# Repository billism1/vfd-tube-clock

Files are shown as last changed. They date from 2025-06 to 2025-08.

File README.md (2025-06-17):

# VFD Tube Clock

This project is a WiFi-connected clock that uses an IV-21 VFD (Vacuum Fluorescent Display) tube for the display and a custom PCB controlled by an ESP32 microcontroller. Built with PlatformIO using the Arduino framework, it should work with other ESP32 variants and Arduino-compatible MCUs.

## Design Overview

The PCB is designed around the Seeeduino ESP32-C3 devboard but can be adapted for other microcontrollers. The schematic and PCB design files were created using KiCad 9.0, with firmware development in VS Code with PlatformIO.

## Project Background

This is the first time I've had PCBs printed. I've been a software developer for many years and have been dabbling in electronics as a hobby over the past couple of years. I've been fascinated by vintage display technology - there's something captivating about the warm glow and classic look of old tube displays, plus those beautiful colors that display tubes like Nixie tubes and VFDs produce. I love the idea of bridging old and new technology by controlling these vintage displays with modern microcontrollers and WiFi connectivity.

**Current Status:** I'm actively refining the PCB design based on initial testing. The photos and videos below show the first prototype batch of 5 PCBs, while the KiCad files reflect ongoing improvements to the design.

## Project Photos

<div align="center">
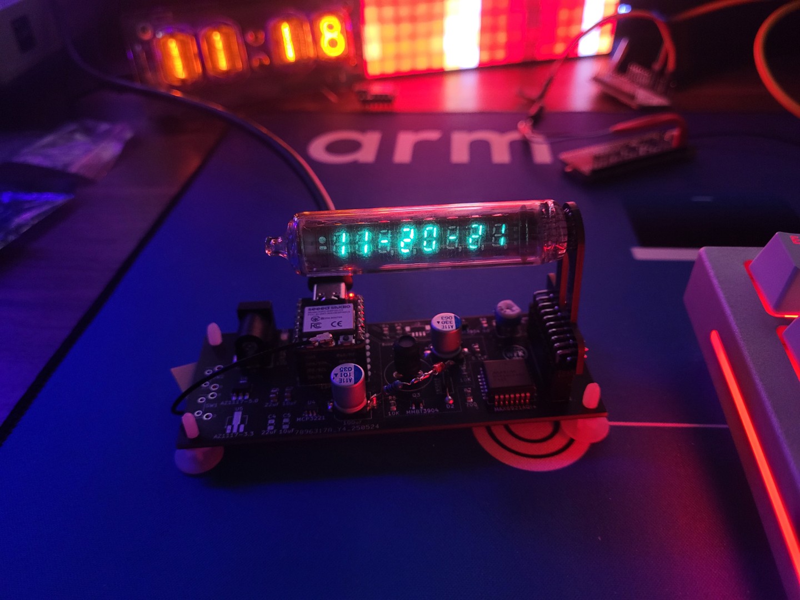
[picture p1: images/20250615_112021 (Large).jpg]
VFD Clock Front View 1

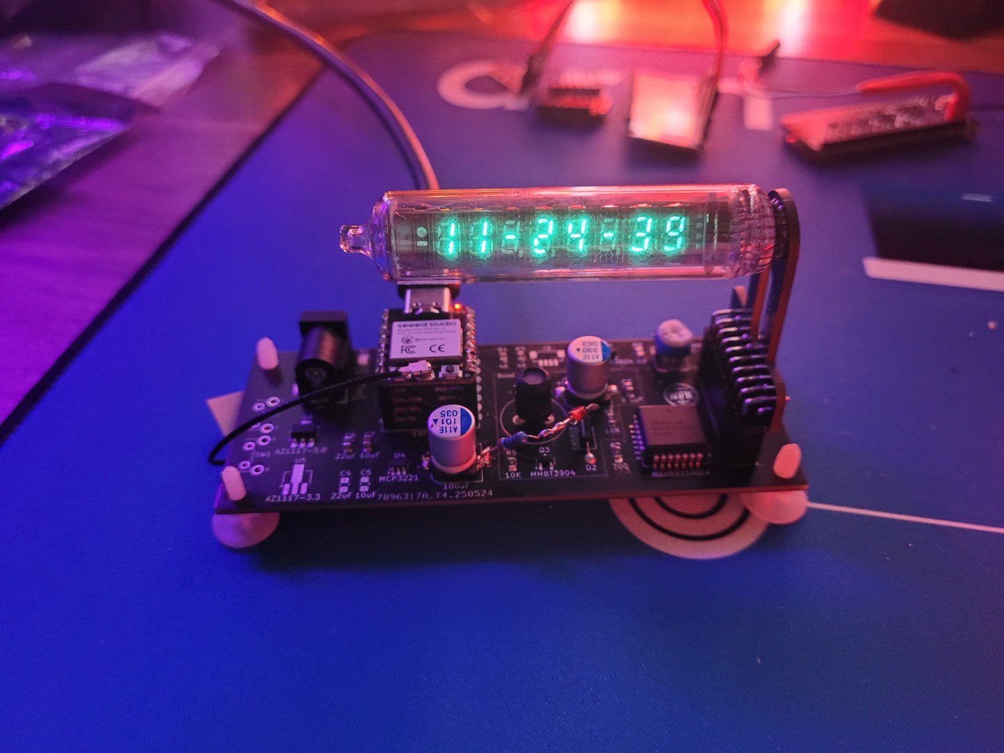
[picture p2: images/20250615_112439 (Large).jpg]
VFD Clock Front View 2

</div>

## Web Interface

Though most of the source code I wrote myself, one of my weak areas is web UI design. I used an LLM (claude.ai) to generate a Soviet themed web UI for controlling the clock over WiFi. Soviet - because these IV-21 VFD tubes were manufactured in Soviet USSR.

**[View Web Interface Screenshots in images dir →](images/)**

## Video

VFD Clock Demo Video (https://youtu.be/QAAFPpQU498)

*Click to watch the demo video*

## How VFD Tubes Work

VFDs use phosphor materials, typically zinc oxide (ZnO) doped with zinc sulfide or other compounds, that emit light when struck by electrons from a heated filament cathode. The phosphor coating on the anode segments converts the electron energy into visible light, usually producing a characteristic blue-green glow, though the exact color depends on the specific phosphor formulation. The IV-21 specifically uses a zinc-based phosphor that creates its distinctive aqua-blue appearance.

The electrical requirements involve multiple voltages: a low filament voltage to heat the cathode (~2.5V DC for the IV-21), and higher anode/grid voltages to accelerate electrons toward the phosphor-coated segments (typically ~27V DC for the IV-21).

Multiplexing is the key technique that makes multi-digit VFD clocks practical - instead of driving all digits simultaneously (which would require complex, expensive circuitry), we rapidly cycle through each digit position, lighting only one at a time. By switching between digits faster than your eye can detect (typically 100Hz or higher), each digit appears continuously lit even though it's only powered for a fraction of the time. This creates the illusion of a stable, solid display across all digits while dramatically simplifying the driver electronics.

## Key Circuit Design Components

### Voltage Booster Circuit
The VFD needs 27V but our power supply only provides 5V, so we need a boost converter to step up the voltage. This circuit works like a voltage pump - it stores energy in an inductor coil when a transistor switches on, then releases that energy at a higher voltage when the transistor switches off. A diode ensures the boosted voltage flows in the right direction, and the ESP32 generates the rapid on/off switching signal (PWM) that makes it all work.
The circuit takes our 5V input and pumps it up to the 27V needed by the MAX6921 driver chip, which then distributes power to light up the VFD segments.

### MAX6921 VFD Driver
The MAX6921 IC serves as the interface between the microcontroller and VFD tube. It receives 3 bytes of data from the ESP32 telling it which segments to illuminate, then distributes the boosted 27V to the appropriate pins at precise timing intervals for proper message display. Multiple MAX6921s can be chained together for tubes with more digits or multiple tubes.

## Software Features

### Core Functionality
- **WiFi Connectivity:** Automatic connection to configured network
- **NTP Time Sync:** Retrieves accurate time from "pool.ntp.org"
- **Web Server:** Built-in HTTP server for device control
- **Multiple Display Modes:**
  - Time display mode
  - Custom message mode
  - "Flash message" mode with glitchy visual effects

### Flash Message Mode
As a novelty feature (which can be disabled), the clock occasionally displays random words that appear to "glitch" into existence—brief flashes of random characters before settling on the final message for a brief period, creating a subliminal effect. The word selection (easily changed in code) and styling pay homage to the Soviet heritage of these VFD tubes.

## Planned Improvements

### Hardware Enhancements
- **Better Voltage Regulation**
- **Multi-digit Support:** Extend design for tubes with more digits (IV-27 with 13 digits)

### Software Features
- **Better Wifi Management:** Default to AP mode for after compilation WiFi configuration
- **Text Scrolling:** Support for messages longer than 8 characters
- **Smart PWM Control:** Implement PID algorithm for voltage regulation
- **Enhanced Web UI:** Additional control options and settings
- **Button Integration:** Assign meaningful functions to hardware buttons which are not programmed to do anything currently

## Acknowledgments

This project was heavily inspired by and references the excellent work of:

- **[Tiny IV-21 VFD Clock](https://hackaday.io/project/167749-tiny-iv-21-vfd-clock)** - Original design inspiration. At least this was the first similar project that I came across. Uses an Atmega328P microcontroller and external (to the microcontroller module) RTC (real-time clock) component.
- **[Tiny IV-21 VFD Clock with ESP32](https://hackaday.io/project/202799-tiny-iv-21-vfd-clock-with-esp32)** - ESP32 implementation inspired from the above mentioned "Tiny IV-21 VFD Clock" project. Excludes the external RTC component and uses WiFi/Internet for automatic time synchronization.

Special thanks to the creators of these projects for sharing their knowledge and making this hobby accessible to others.

## Project Organization

### Where to find stuff
- [Main board PCB KiCad design files](./pcb/main-board/)
- [Sub-board PCB (VFD tube holder) design files](./pcb/sub-board/)
- [Main board PCB gerber files (ready to print PCBs)](./pcb-fab/gerber-main-board/)
- [An interactive BOM (Bill of Materials) for the main board](./pcb-fab/gerber-main-board/bom/)
- [Sub-board PCB - VFD tube holder (ready to print PCBs)](./pcb-fab/gerber-sub-board/)
- [Source code](./firmware/) (Built with PlatformIO for simplified dependency management and cross-platform development)

## License

This project is licensed under the MIT License - see the [LICENSE](LICENSE) file for details.

## Contributing

Contributions are welcome! Please feel free to submit pull requests or open issues for bugs and feature requests.

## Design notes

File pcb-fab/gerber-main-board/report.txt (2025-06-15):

Plotted to 'C:\Users\billi\Source\repos\iv21-vfd-clock-with-esp32\pcb\main-board\gerber-output\iv21-vfd-clock-with-esp32-F_Cu.gbr'.
Plotted to 'C:\Users\billi\Source\repos\iv21-vfd-clock-with-esp32\pcb\main-board\gerber-output\iv21-vfd-clock-with-esp32-B_Cu.gbr'.
Plotted to 'C:\Users\billi\Source\repos\iv21-vfd-clock-with-esp32\pcb\main-board\gerber-output\iv21-vfd-clock-with-esp32-F_Paste.gbr'.
Plotted to 'C:\Users\billi\Source\repos\iv21-vfd-clock-with-esp32\pcb\main-board\gerber-output\iv21-vfd-clock-with-esp32-B_Paste.gbr'.
Plotted to 'C:\Users\billi\Source\repos\iv21-vfd-clock-with-esp32\pcb\main-board\gerber-output\iv21-vfd-clock-with-esp32-F_Silkscreen.gbr'.
Plotted to 'C:\Users\billi\Source\repos\iv21-vfd-clock-with-esp32\pcb\main-board\gerber-output\iv21-vfd-clock-with-esp32-B_Silkscreen.gbr'.
Plotted to 'C:\Users\billi\Source\repos\iv21-vfd-clock-with-esp32\pcb\main-board\gerber-output\iv21-vfd-clock-with-esp32-F_Mask.gbr'.
Plotted to 'C:\Users\billi\Source\repos\iv21-vfd-clock-with-esp32\pcb\main-board\gerber-output\iv21-vfd-clock-with-esp32-B_Mask.gbr'.
Plotted to 'C:\Users\billi\Source\repos\iv21-vfd-clock-with-esp32\pcb\main-board\gerber-output\iv21-vfd-clock-with-esp32-Edge_Cuts.gbr'.
Created Gerber job file 'C:\Users\billi\Source\repos\iv21-vfd-clock-with-esp32\pcb\main-board\gerber-output\iv21-vfd-clock-with-esp32-job.gbrjob'.
Info: Done.

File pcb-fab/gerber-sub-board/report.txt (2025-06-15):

Plotted to 'C:\Users\billi\Source\repos\iv21-vfd-clock-with-esp32\pcb-fab\gerber-sub-board\IV-21VFDsub-F_Cu.gbr'.
Plotted to 'C:\Users\billi\Source\repos\iv21-vfd-clock-with-esp32\pcb-fab\gerber-sub-board\IV-21VFDsub-B_Cu.gbr'.
Plotted to 'C:\Users\billi\Source\repos\iv21-vfd-clock-with-esp32\pcb-fab\gerber-sub-board\IV-21VFDsub-F_Paste.gbr'.
Plotted to 'C:\Users\billi\Source\repos\iv21-vfd-clock-with-esp32\pcb-fab\gerber-sub-board\IV-21VFDsub-B_Paste.gbr'.
Plotted to 'C:\Users\billi\Source\repos\iv21-vfd-clock-with-esp32\pcb-fab\gerber-sub-board\IV-21VFDsub-F_Silkscreen.gbr'.
Plotted to 'C:\Users\billi\Source\repos\iv21-vfd-clock-with-esp32\pcb-fab\gerber-sub-board\IV-21VFDsub-B_Silkscreen.gbr'.
Plotted to 'C:\Users\billi\Source\repos\iv21-vfd-clock-with-esp32\pcb-fab\gerber-sub-board\IV-21VFDsub-F_Mask.gbr'.
Plotted to 'C:\Users\billi\Source\repos\iv21-vfd-clock-with-esp32\pcb-fab\gerber-sub-board\IV-21VFDsub-B_Mask.gbr'.
Plotted to 'C:\Users\billi\Source\repos\iv21-vfd-clock-with-esp32\pcb-fab\gerber-sub-board\IV-21VFDsub-Edge_Cuts.gbr'.
Created Gerber job file 'C:\Users\billi\Source\repos\iv21-vfd-clock-with-esp32\pcb-fab\gerber-sub-board\IV-21VFDsub-job.gbrjob'.
Plotted to 'C:\Users\billi\Source\repos\iv21-vfd-clock-with-esp32\pcb-fab\gerber-sub-board\IV-21VFDsub-F_Cu.gbr'.
Plotted to 'C:\Users\billi\Source\repos\iv21-vfd-clock-with-esp32\pcb-fab\gerber-sub-board\IV-21VFDsub-B_Cu.gbr'.
Plotted to 'C:\Users\billi\Source\repos\iv21-vfd-clock-with-esp32\pcb-fab\gerber-sub-board\IV-21VFDsub-F_Paste.gbr'.
Plotted to 'C:\Users\billi\Source\repos\iv21-vfd-clock-with-esp32\pcb-fab\gerber-sub-board\IV-21VFDsub-B_Paste.gbr'.
Plotted to 'C:\Users\billi\Source\repos\iv21-vfd-clock-with-esp32\pcb-fab\gerber-sub-board\IV-21VFDsub-F_Silkscreen.gbr'.
Plotted to 'C:\Users\billi\Source\repos\iv21-vfd-clock-with-esp32\pcb-fab\gerber-sub-board\IV-21VFDsub-B_Silkscreen.gbr'.
Plotted to 'C:\Users\billi\Source\repos\iv21-vfd-clock-with-esp32\pcb-fab\gerber-sub-board\IV-21VFDsub-F_Mask.gbr'.
Plotted to 'C:\Users\billi\Source\repos\iv21-vfd-clock-with-esp32\pcb-fab\gerber-sub-board\IV-21VFDsub-B_Mask.gbr'.
Plotted to 'C:\Users\billi\Source\repos\iv21-vfd-clock-with-esp32\pcb-fab\gerber-sub-board\IV-21VFDsub-Edge_Cuts.gbr'.
Created Gerber job file 'C:\Users\billi\Source\repos\iv21-vfd-clock-with-esp32\pcb-fab\gerber-sub-board\IV-21VFDsub-job.gbrjob'.
Info: Done.
Info: Done.

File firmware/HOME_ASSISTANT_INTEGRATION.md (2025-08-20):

# VFD Tube Clock - Home Assistant Integration

This document provides instructions for integrating the VFD Tube Clock with Home Assistant for remote control and monitoring.

## Features

### VFD Filament Control
- **Remote Control**: Toggle the VFD filament on/off via Home Assistant
- **Physical Button Control**: On-board button support for local control
- **REST API**: HTTP endpoints for programmatic control and status monitoring
- **Real-time Status**: Live monitoring of all clock parameters

### Physical Button Support
- **Button 1 (SW1)**: Connected to D1/A1 pin - toggles VFD filament state
- **Button 2 (SW2)**: Connected to D0/A0 pin - toggles display mode (time/custom text)
- **Hardware Debouncing**: 50ms debounce delay prevents multiple triggers
- **Internal Pull-ups**: Buttons connect to ground when pressed (no external resistors needed)

### Home Assistant Integration Options
- **REST API Integration**: Direct HTTP communication with the clock
- **Status Monitoring**: Real-time status of all clock systems
- **Automation Support**: Scheduled on/off cycles and monitoring

## API Endpoints

### GET /status
Returns comprehensive status in JSON format:
```json
{
  "filament_state": true,
  "display_mode": "time",
  "custom_text": "HELLO   ",
  "flash_messages_enabled": true,
  "current_time": "14:30:25",
  "wifi_connected": true,
  "ip_address": "192.168.86.104",
  "uptime_ms": 123456789,
  "boost_duty_cycle": 110,
  "target_voltage": 30.0
}
```

### GET /filament/toggle
Toggles the VFD filament state and returns confirmation:
```json
{
  "filament_state": false,
  "message": "Filament disabled"
}
```

## Setup Instructions

### Prerequisites
- VFD Tube Clock with updated firmware flashed to ESP32
- Home Assistant instance running on your network
- Clock and Home Assistant on the same network

### Integration Setup

#### REST Integration (Recommended)
The VFD Tube Clock uses a REST API approach for Home Assistant integration, which preserves all custom functionality while providing full remote control.

1. **Identify Clock IP Address**
   - Check your router's DHCP client list
   - Monitor serial output during clock startup
   - Visit the clock's web interface to confirm connectivity

2. **Configure Home Assistant**
   - Copy the configuration from `home-assistant-config.yaml`
   - Add it to your Home Assistant `configuration.yaml` file
   - Replace `192.168.86.104` with your clock's actual IP address
   - Restart Home Assistant

3. **Verify Integration**
   - Check Developer Tools → States for new entities
   - Test the filament control switch
   - Monitor status sensors for real-time updates

## Physical Button Configuration

### Default Button Functions
- **Button 1 (SW1)**: Toggles VFD filament on/off
- **Button 2 (SW2)**: Toggles between time display and custom text display

### Hardware Requirements
- Tactile momentary switches connected to D1/A1 (SW1) and D0/A0 (SW2)
- Switches should connect the respective pins to ground when pressed
- No external pull-up resistors required (internal pull-ups enabled)

### Customizing Button Functions
Button handlers can be modified in the firmware source code:

```cpp
void handleButton1Press() {
  // Default: Toggle filament
  // Modify this function for custom behavior
}

void handleButton2Press() {
  // Default: Toggle display mode  
  // Modify this function for custom behavior
}
```

### Alternative Button Functions
Consider implementing these features:
- Brightness level cycling
- Flash message toggle
- Configuration mode entry
- Time zone cycling
- 12/24 hour format toggle
- Voltage target adjustment
- WiFi configuration reset

## Home Assistant Entities

After successful integration, the following entities will be available:

### Controls
- `switch.vfd_clock_filament_control` - Toggle VFD filament on/off
- `rest_command.vfd_clock_toggle_filament` - Direct API command

### Sensors
- `sensor.vfd_clock_status` - Main status sensor with current time
- `binary_sensor.vfd_clock_filament` - Filament state indicator
- `binary_sensor.vfd_clock_wifi_connected` - Network connectivity status
- `sensor.vfd_clock_display_mode` - Current display mode (time/custom)
- `sensor.vfd_clock_uptime` - Device uptime in seconds
- `sensor.vfd_clock_boost_duty_cycle` - Boost converter duty cycle
- `sensor.vfd_clock_target_voltage` - Target voltage setting

## Example Automations

### Scheduled Power Management
```yaml
automation:
  - alias: "VFD Clock - Night Mode"
    trigger:
      platform: time
      at: "23:00:00"
    action:
      service: switch.turn_off
      target:
        entity_id: switch.vfd_clock_filament_control

  - alias: "VFD Clock - Morning Activation"
    trigger:
      platform: time
      at: "07:00:00"
    action:
      service: switch.turn_on
      target:
        entity_id: switch.vfd_clock_filament_control
```

### Connectivity Monitoring
```yaml
automation:
  - alias: "VFD Clock - Offline Notification"
    trigger:
      platform: state
      entity_id: binary_sensor.vfd_clock_wifi_connected
      to: "off"
      for: "00:05:00"
    action:
      service: notify.persistent_notification
      data:
        title: "VFD Clock Offline"
        message: "VFD Clock has been offline for 5 minutes"
```

## Troubleshooting

### Common Issues

#### Clock Not Responding
- Check the clock's IP address hasn't changed
- Check network connectivity between Home Assistant and clock
- Test API endpoints directly: `curl http://[clock-ip]/status`

#### Entities Not Updating
- Check Home Assistant logs for REST sensor errors
- Adjust `scan_interval` in configuration if needed
- Check timeout settings for your network

#### Button Functionality Issues
- Check button hardware connections:
  - SW1 → D1/A1 pin (GPIO2)
  - SW2 → D0/A0 pin (GPIO3)
- Monitor serial output at 115200 baud for button press confirmations
- Ensure buttons connect pins to ground when pressed

### Debugging Tools

#### Serial Monitor
Enable debug output to monitor:
- Button press events
- Filament state changes  
- Network connectivity
- API request handling

#### Web Interface
Access the clock's built-in web interface:
- Navigate to `http://[clock-ip]/`
- Verify current status and settings
- Test manual control functions

#### API Testing
Test endpoints directly:
```bash
# Get current status
curl http://[clock-ip]/status

# Toggle filament
curl http://[clock-ip]/filament/toggle
```

## Hardware Requirements

### Circuit Board Connections
- **VFD Filament Control**: D2 pin (GPIO4) drives transistor circuit
- **Button 1 (SW1)**: D1/A1 pin (GPIO2) with internal pull-up
- **Button 2 (SW2)**: D0/A0 pin (GPIO3) with internal pull-up
- **Power**: Standard ESP32-C3 power requirements

### Network Requirements
- 2.4GHz WiFi network access
- Home Assistant on same network segment
- Stable network connection for reliable API communication

## Development and Customization

### Extending Functionality
The firmware provides a foundation for additional features:
- Custom button behaviors via `handleButton1Press()` and `handleButton2Press()`
- Additional API endpoints for new functionality
- Extended status reporting and monitoring
- Integration with other home automation systems

### Contributing
This is an open-source project. Contributions welcome for:
- Additional Home Assistant integrations
- Extended API functionality
- Bug fixes and improvements
- Documentation updates

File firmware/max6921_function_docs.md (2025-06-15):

# MAX6921 VFD Driver Function Documentation

This document provides comprehensive documentation for all functions in the MAX6921 VFD (Vacuum Fluorescent Display) driver library.

## Overview

The MAX6921 is a 20-output, 76V, serial-interfaced VFD tube driver. This library provides functions to initialize, configure, and control VFD displays using 7-segment characters with support for multiple digits and chips.

## Static Variables and Arrays

### `segment_definitions[128]`
- **Type**: `static const char*`
- **Purpose**: Maps ASCII characters (0-127) to their corresponding segment patterns
- **Format**: Each string contains letters A-H representing which segments to illuminate
- **Example**: `'8'` maps to `"AFBGECD"` (all segments except H/period)

## Functions

### `init_segment_definitions()`
```c
static void init_segment_definitions()
```

**Purpose**: Initializes the segment definitions array with character-to-segment mappings.

**Behavior**:
- Uses static initialization flag to prevent multiple initializations
- Clears all 128 array positions to NULL initially
- Maps digits 0-9, letters A-Z, and special characters to their 7-segment representations
- Supports segments A-G (standard 7-segment) plus H (decimal point/period)

**Segment Layout**:
```
 AAA
F   B
 GGG
E   C
 DDD  H
```

**Character Examples**:
- `'0'`: `"DEFABC"` (segments D,E,F,A,B,C)
- `'8'`: `"AFBGECD"` (all segments except H)
- `'A'`: `"EGFABC"` (segments E,G,F,A,B,C)
- `' '`: `""` (blank/space)

---

### `vfd_init()`
```c
void vfd_init(vfd_t *vfd, pin_config_t *digits, int num_digits, 
              pin_config_t *segments, int num_segments)
```

**Purpose**: Initializes the VFD display structure and hardware configuration.

**Parameters**:
- `vfd`: Pointer to VFD structure to initialize
- `digits`: Array of pin configurations for digit control
- `num_digits`: Number of digits in the display
- `segments`: Array of pin configurations for segment control (A-H)
- `num_segments`: Number of segments (typically 8)

**Behavior**:
- Initializes segment definitions (calls `init_segment_definitions()`)
- Clears and sets up the VFD structure
- Sets default SPI frequency to 500kHz
- Copies digit and segment pin configurations
- Builds list of unique CS (Chip Select) pins from both digits and segments
- Initializes CS pins as OUTPUT and sets them HIGH (inactive)
- Builds internal pin mapping tables
- Sets initial display buffer to " Init "
- Assigns default SPI interface

**Side Effects**:
- Modifies GPIO pin modes for CS pins
- Initializes internal data structures

---

### `vfd_init_spi()`
```c
void vfd_init_spi(vfd_t *vfd, uint32_t frequency)
```

**Purpose**: Initializes the SPI interface with specified frequency.

**Parameters**:
- `vfd`: Pointer to initialized VFD structure
- `frequency`: SPI clock frequency in Hz

**Behavior**:
- Sets the SPI frequency in the VFD structure
- Calls `SPI.begin()` to initialize the SPI peripheral

**Notes**:
- Must be called after `vfd_init()`
- Typical frequencies: 100kHz - 1MHz depending on VFD requirements

---

### `build_pin_maps()`
```c
void build_pin_maps(vfd_t *vfd)
```

**Purpose**: Builds internal pin mapping tables for efficient data transmission.

**Parameters**:
- `vfd`: Pointer to initialized VFD structure

**Behavior**:
- Creates digit pin maps for each display digit
- Creates segment pin maps for each segment (A-H)
- Handles bit order reversal (MAX6921 uses reverse bit order 19-0)
- Maps logical pin numbers to physical byte/bit positions
- Organizes data by chip index for multi-chip displays

**Algorithm**:
1. For each digit/segment, find corresponding chip index
2. Calculate true bit order: `abs(pin_number - 23)`
3. Calculate target byte: `true_order / 8`
4. Calculate target bit: `true_order % 8`
5. Set appropriate bit in mapping table

**Data Structure**: Creates 3D arrays `[digit/segment][chip][byte]` for fast lookup

---

### `vfd_set_text()`
```c
void vfd_set_text(vfd_t *vfd, const char *text)
```

**Purpose**: Sets the text to be displayed on the VFD.

**Parameters**:
- `vfd`: Pointer to VFD structure
- `text`: Null-terminated string to display

**Behavior**:
- Copies input text to internal print buffer
- Limits text length to `MAX_PRINT_BUFFER - 2` characters
- Converts all characters to uppercase
- Appends a space character to prevent brightness issues on last character
- Null-terminates the buffer

**Notes**:
- Text is processed during `vfd_draw()` calls
- Supports decimal points when '.' follows a character
- Unsupported characters display as blank

---

### `concat_pins()`
```c
void concat_pins(uint8_t result[MAX_CHIPS][BYTES_PER_CHIP], 
                 uint8_t src1[MAX_CHIPS][BYTES_PER_CHIP], 
                 uint8_t src2[MAX_CHIPS][BYTES_PER_CHIP])
```

**Purpose**: Combines two pin data arrays using modulo arithmetic.

**Parameters**:
- `result`: Output array for combined data
- `src1`: First source array
- `src2`: Second source array

**Behavior**:
- Performs element-wise addition of two 3D arrays
- Uses modulo 256 to prevent overflow
- Combines digit and segment data for final output

**Formula**: `result[chip][byte] = (src1[chip][byte] + src2[chip][byte]) % 256`

**Use Case**: Combines digit selection pins with segment data pins

---

### `get_char_segments()`
```c
void get_char_segments(vfd_t *vfd, char c, uint8_t result[MAX_CHIPS][BYTES_PER_CHIP])
```

**Purpose**: Converts a character to its corresponding segment pin data.

**Parameters**:
- `vfd`: Pointer to VFD structure
- `c`: Character to convert
- `result`: Output array for segment pin data

**Behavior**:
- Clears result array initially
- Looks up character in segment definitions (ASCII 0-127 only)
- For each segment letter in the definition:
  - Maps A-H to segment indices 0-7
  - ORs the corresponding segment pin data into result
- Handles undefined characters by returning empty result

**Segment Mapping**:
- 'A' → index 0, 'B' → index 1, ..., 'H' → index 7

**Output**: 3D array with bits set for required segment pins across all chips

---

### `vfd_draw()`
```c
void vfd_draw(vfd_t *vfd)
```

**Purpose**: Main display refresh function that outputs current text to the VFD hardware.

**Parameters**:
- `vfd`: Pointer to initialized VFD structure

**Behavior**:
- Processes each digit position in sequence
- Handles decimal point processing (periods modify previous character)
- Combines digit selection and segment data
- Transmits data via SPI to all chips
- Includes debug output (when DEBUG is defined)

**Algorithm**:
1. For each digit position:
   - Get digit selection pin data
   - Get character segment data from text buffer
   - Handle decimal point if next character is '.'
   - Combine digit and segment data
   - Transmit 24 bits (3 bytes) to each chip via SPI

**SPI Protocol**:
- Uses MSB first, SPI Mode 0
- CS pin LOW during transmission, HIGH when idle
- Sends 3 bytes per chip (24 bits total)

**Debug Features**:
- Prints display buffer contents every 2 seconds
- Shows hex data being sent to each chip
- Helps troubleshoot display issues

**Performance**: Optimized for real-time display refresh in main loop

## Usage Example

```c
// Initialize VFD with 4 digits and 8 segments
pin_config_t digits[4] = {{cs_pin: 10, pin_number: 0}, ...};
pin_config_t segments[8] = {{cs_pin: 10, pin_number: 8}, ...};

vfd_t my_vfd;
vfd_init(&my_vfd, digits, 4, segments, 8);
vfd_init_spi(&my_vfd, 500000);

// Display text
vfd_set_text(&my_vfd, "12.34");

// In main loop
while(1) {
    vfd_draw(&my_vfd);
    delay(1);
}
```

## Technical Notes

- **Multiplexing**: Display uses time-division multiplexing, requiring continuous refresh
- **Bit Order**: MAX6921 requires reverse bit order (pin 19 = bit 0)
- **Decimal Points**: Handled by combining '.' with previous character
- **Multi-chip**: Supports multiple MAX6921 chips for larger displays
- **SPI Speed**: 500kHz default, adjustable based on display requirements

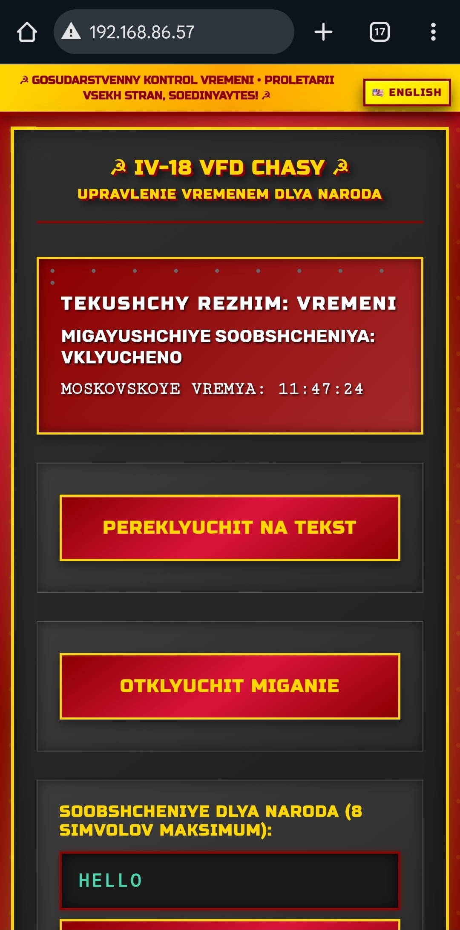
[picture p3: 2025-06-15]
images/orig/WebUI_Russian.jpg

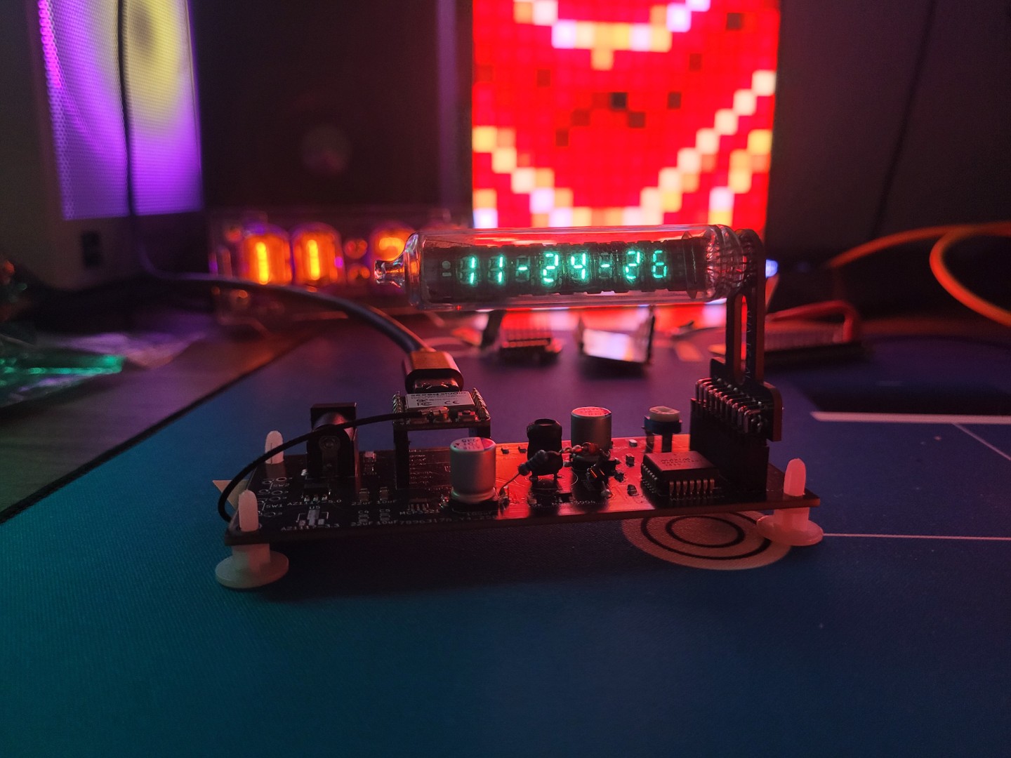
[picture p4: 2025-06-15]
images/20250615_112425 (Large).jpg

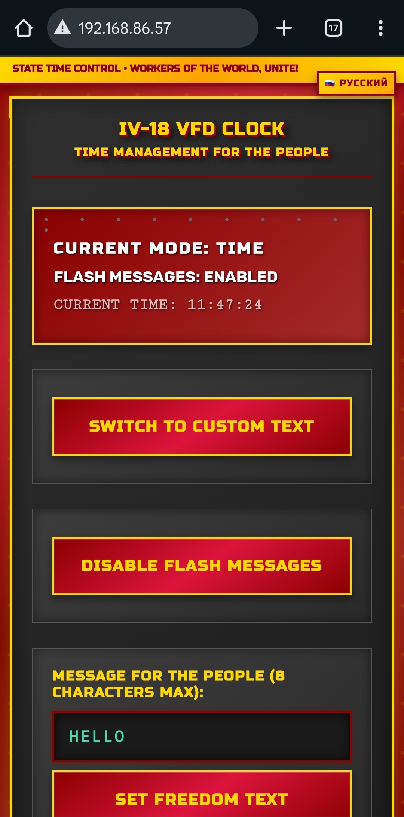
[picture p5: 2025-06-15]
images/orig/WebUI_English.jpg

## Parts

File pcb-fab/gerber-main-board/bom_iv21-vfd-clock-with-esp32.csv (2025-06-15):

Id | Designator | Footprint | Quantity | Designation | Supplier and ref
1 | R5,R1,R6 | R_0805_2012Metric_Pad1.20x1.40mm_HandSolder | 3 | 10K
2 | D1 | LED_1206_3216Metric | 1 | LED
3 | U1 | PLCC127P1244X1244X457-28N | 1 | MAX6921AQI_
4 | Q3 | SOT-23-3 | 1 | MMBT3904
5 | J1 | PinHeader_2x10_P2.54mm_Vertical | 1 | Conn_02x10_Odd_Even
6 | C1 | CP_Elec_8x10.5 | 1 | 33uF
7 | J4 | BarrelJack_Wuerth_6941xx301002 | 1 | Barrel_Jack_MountingPin
8 | U4 | SOT-23-5 | 1 | MCP3221
9 | D2 | D_DO-41_SOD81_P10.16mm_Horizontal | 1 | 1N5818
10 | U2 | MOUDLE14P-SMD-2.54-21X17.8MM (With Through Holes) | 1 | MOUDLE-SEEEDUINO-XIAO-ESP32C3
11 | SW2,SW1 | SW_Tactile_SPST_Angled_PTS645Vx58-2LFS | 2 | SW_SPST
12 | R4,R3 | R_0805_2012Metric_Pad1.20x1.40mm_HandSolder | 2 | 4K
13 | RV1 | Potentiometer_Runtron_RM-065_Vertical | 1 | 80
14 | C3 | CP_Elec_8x10.5 | 1 | 100uF
15 | U5 | SOT-89-3_Handsoldering | 1 | AZ1117-3.3
16 | Q4 | SOT-23 | 1 | MMBT3904
17 | U6 | SOT-89-3_Handsoldering | 1 | AZ1117-5.0
18 | C6,C4 | R_0805_2012Metric_Pad1.20x1.40mm_HandSolder | 2 | 22uF
19 | R7 | R_0805_2012Metric_Pad1.20x1.40mm_HandSolder | 1 | 700
20 | C7,C5 | R_0805_2012Metric_Pad1.20x1.40mm_HandSolder | 2 | 10uF
21 | R8 | R_0805_2012Metric_Pad1.20x1.40mm_HandSolder | 1 | 80
22 | C2 | R_0805_2012Metric_Pad1.20x1.40mm_HandSolder | 1 | 0.1uF
23 | L1 | L_Radial_D12.0mm_P5.00mm_Fastron_11P | 1 | 2mH
24 | J2 | ADAFRUIT_4328 | 1 | 4328
25 | R2 | R_0805_2012Metric_Pad1.20x1.40mm_HandSolder | 1 | 100

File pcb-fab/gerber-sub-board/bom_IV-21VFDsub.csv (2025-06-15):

Id | Designator | Footprint | Quantity | Designation | Supplier and ref
1 | U$1 | IV-21VFD | 1 | IV-21VFD
2 | X1 | TSW-110-XX-G-D_184 | 1 | TSW-110-07-G-D

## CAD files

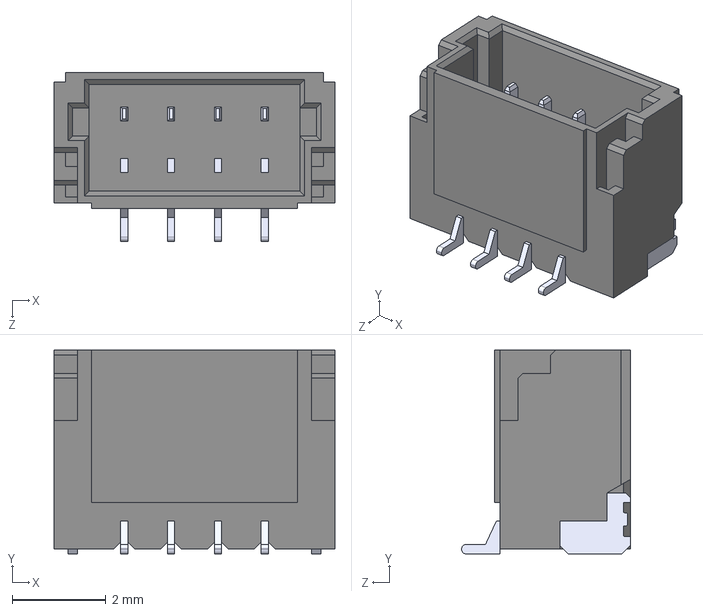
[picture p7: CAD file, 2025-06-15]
pcb/main-board/kicad-symbols/JST SH 4-pin 4328/4328.step
6.00 x 4.35 x 3.60 mm

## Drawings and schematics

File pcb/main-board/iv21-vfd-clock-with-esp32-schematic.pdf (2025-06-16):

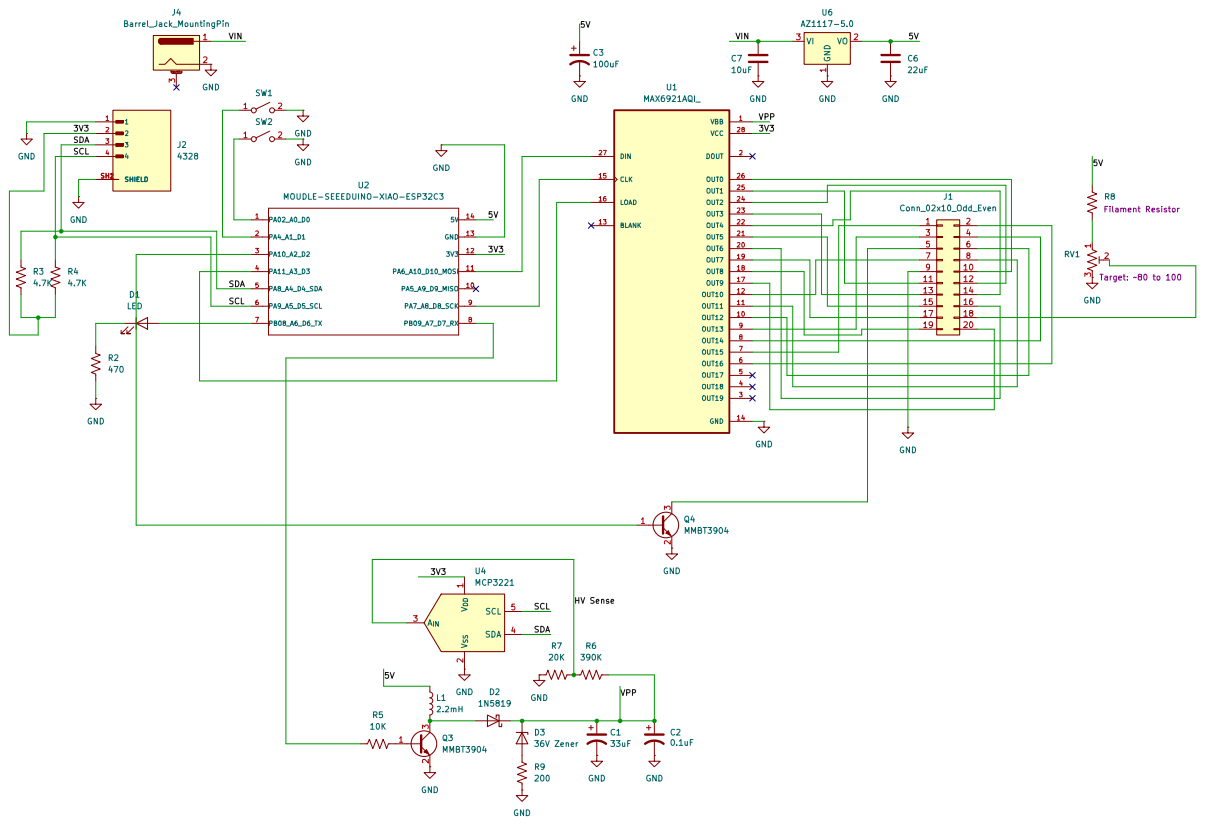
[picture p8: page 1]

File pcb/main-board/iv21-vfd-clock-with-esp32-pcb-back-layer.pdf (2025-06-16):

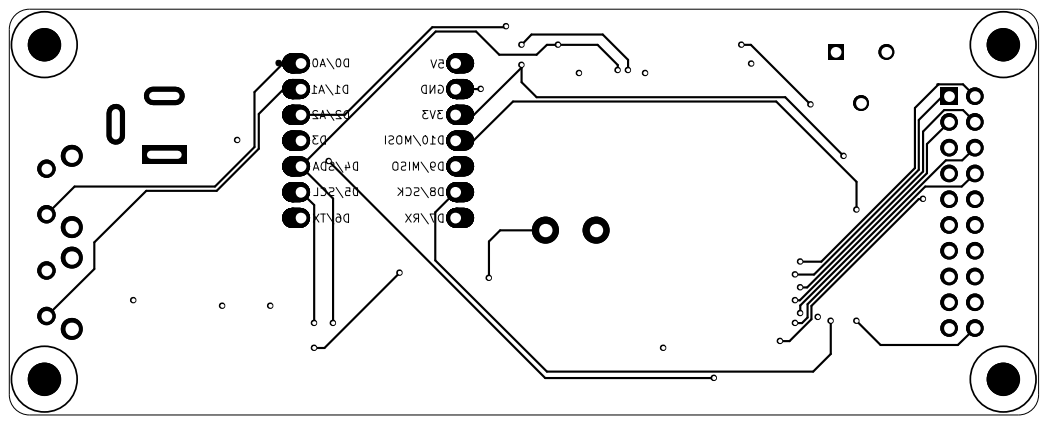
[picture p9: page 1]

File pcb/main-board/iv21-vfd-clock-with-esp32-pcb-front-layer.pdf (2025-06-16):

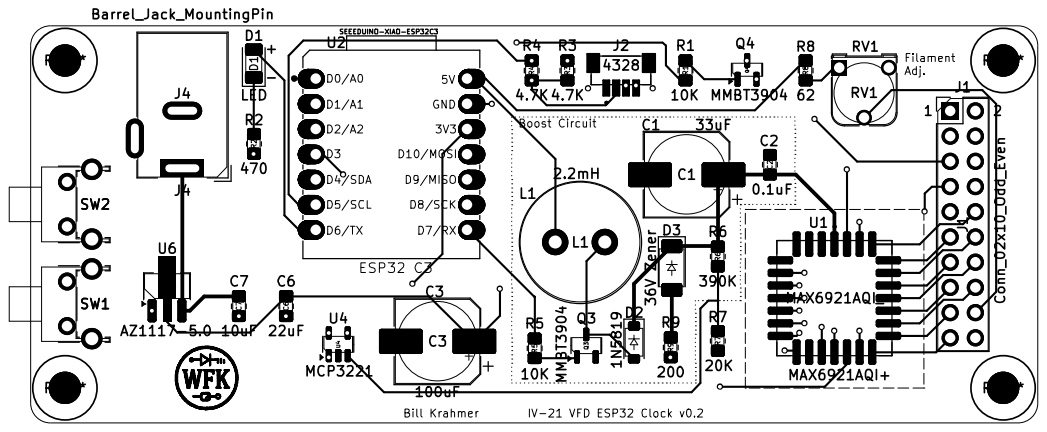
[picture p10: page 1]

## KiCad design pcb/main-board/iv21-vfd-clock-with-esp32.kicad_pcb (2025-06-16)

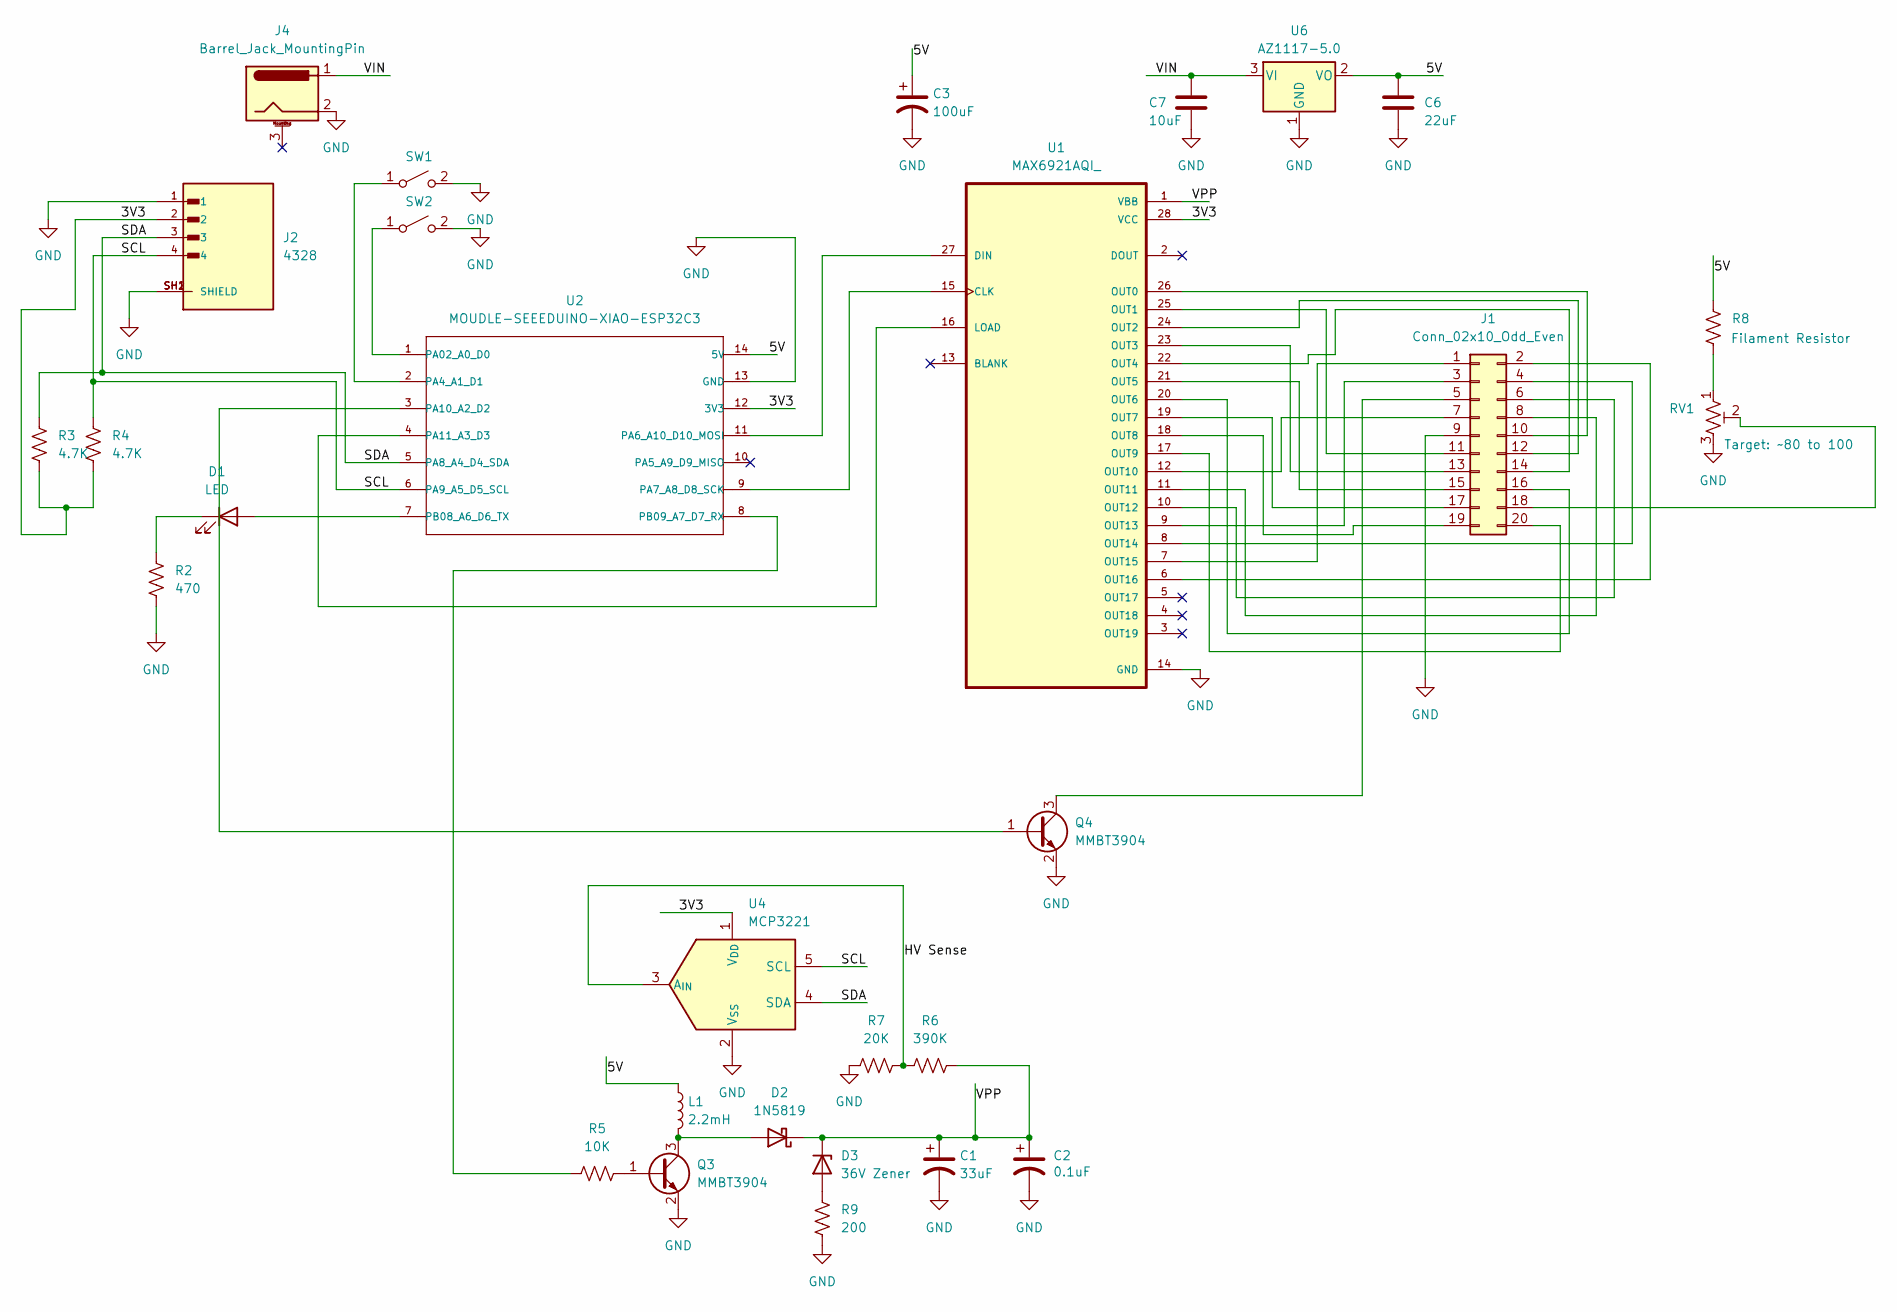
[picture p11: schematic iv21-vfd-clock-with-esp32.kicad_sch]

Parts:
C1: 33uF; CP_Elec_8x10.5
C2: 0.1uF; R_0805_2012Metric_Pad1.20x1.40mm_HandSolder
C3: 100uF; CP_Elec_8x10.5
C6: 22uF; R_0805_2012Metric_Pad1.20x1.40mm_HandSolder
C7: 10uF; R_0805_2012Metric_Pad1.20x1.40mm_HandSolder
D1: LED; LED_1206_3216Metric
D2: 1N5819; D_SOD-123
D3: 36V Zener; D_SOD-128
J1: Conn_02x10_Odd_Even; PinHeader_2x10_P2.54mm_Vertical
J2: 4328; ADAFRUIT_4328; PARTREV 23/3/21
J4: Barrel_Jack_MountingPin; BarrelJack_Wuerth_6941xx301002
L1: 2.2mH; L_Radial_D12.0mm_P5.00mm_Fastron_11P
Q3: MMBT3904; SOT-23-3
Q4: MMBT3904; SOT-23
R2: 470; R_0805_2012Metric_Pad1.20x1.40mm_HandSolder
R3, R4: 4.7K; R_0805_2012Metric_Pad1.20x1.40mm_HandSolder
R5: 10K; R_0805_2012Metric_Pad1.20x1.40mm_HandSolder
R6: 390K; R_0805_2012Metric_Pad1.20x1.40mm_HandSolder
R7: 20K; R_0805_2012Metric_Pad1.20x1.40mm_HandSolder
R8: 2K; R_0805_2012Metric_Pad1.20x1.40mm_HandSolder
R9: 200; R_0805_2012Metric_Pad1.20x1.40mm_HandSolder
RV1: 80; Potentiometer_Runtron_RM-065_Vertical
SW1, SW2: SW_SPST; SW_Tactile_SPST_Angled_PTS645Vx58-2LFS
U1: MAX6921AQI_; PLCC127P1244X1244X457-28N; DIGI-KEY_PART_NUMBER MAX6921AQI+-ND
U2: MOUDLE-SEEEDUINO-XIAO-ESP32C3; MOUDLE14P-SMD-2.54-21X17.8MM (With Through Holes)
U4: MCP3221; SOT-23-5
U6: AZ1117-5.0; SOT-89-3_Handsoldering

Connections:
/3V3: J2.2, R3.2, R4.2, U1.28 (VCC), U2.12 (3V3), U4.1 (V_{DD})
/5V: C3.1, C6.1, L1.1, R8.1, U2.14 (5V), U6.2 (VO)
/HV Sense: R6.1, R7.2, U4.3 (A_{IN})
/SCL: J2.4, R4.1, U2.6 (PA9_A5_D5_SCL), U4.5 (SCL)
/SDA: J2.3, R3.1, U2.5 (PA8_A4_D4_SDA), U4.4 (SDA)
/VIN: C7.1, J4.1, U6.3 (VI)
/VPP: C1.1, C2.1, D2.1 (K), D3.1 (K), R6.2, U1.1 (VBB)
GND: C1.2, C2.2, C3.2, C6.2, C7.2, J1.9, J2.1, J2.SH1 (SHIELD), J2.SH2 (SHIELD), J4.2, Q3.2 (E), Q4.2 (E), R2.2, R7.1, R9.2, RV1.3, SW1.2 (B), SW2.2 (B), U1.14 (GND), U2.13 (GND), U4.2 (V_{SS}), U6.1 (GND)
unnamed: D1.2 (A), U2.7 (PB08_A6_D6_TX)
unnamed: D1.1 (K), R2.1
unnamed: D2.2 (A), L1.2, Q3.3 (C)
unnamed: D3.2 (A), R9.1
unnamed: J1.1, U1.7 (OUT15)
unnamed: J1.2, U1.6 (OUT16)
unnamed: J1.3, U1.9 (OUT13)
unnamed: J1.4, U1.8 (OUT14)
unnamed: J1.5, Q4.3 (C)
unnamed: J1.6, U1.10 (OUT12)
unnamed: J1.7, U1.12 (OUT10)
unnamed: J1.8, U1.11 (OUT11)
unnamed: J1.10, U1.26 (OUT0)
unnamed: J1.11, U1.25 (OUT1)
unnamed: J1.12, U1.24 (OUT2)
unnamed: J1.13, U1.23 (OUT3)
unnamed: J1.14, U1.22 (OUT4)
unnamed: J1.15, U1.21 (OUT5)
unnamed: J1.16, U1.20 (OUT6)
unnamed: J1.17, U1.19 (OUT7)
unnamed: J1.18, RV1.2
unnamed: J1.19, U1.18 (OUT8)
unnamed: J1.20, U1.17 (OUT9)
unnamed: Q3.1 (B), R5.2
unnamed: R8.2, RV1.1
unnamed: SW1.1 (A), U2.2 (PA4_A1_D1)
unnamed: SW2.1 (A), U2.1 (PA02_A0_D0)
unnamed: U1.15 (CLK), U2.9 (PA7_A8_D8_SCK)
unnamed: U1.27 (DIN), U2.11 (PA6_A10_D10_MOSI)
unnamed: U1.16 (LOAD), U2.4 (PA11_A3_D3)
unnamed: R5.1, U2.8 (PB09_A7_D7_RX)

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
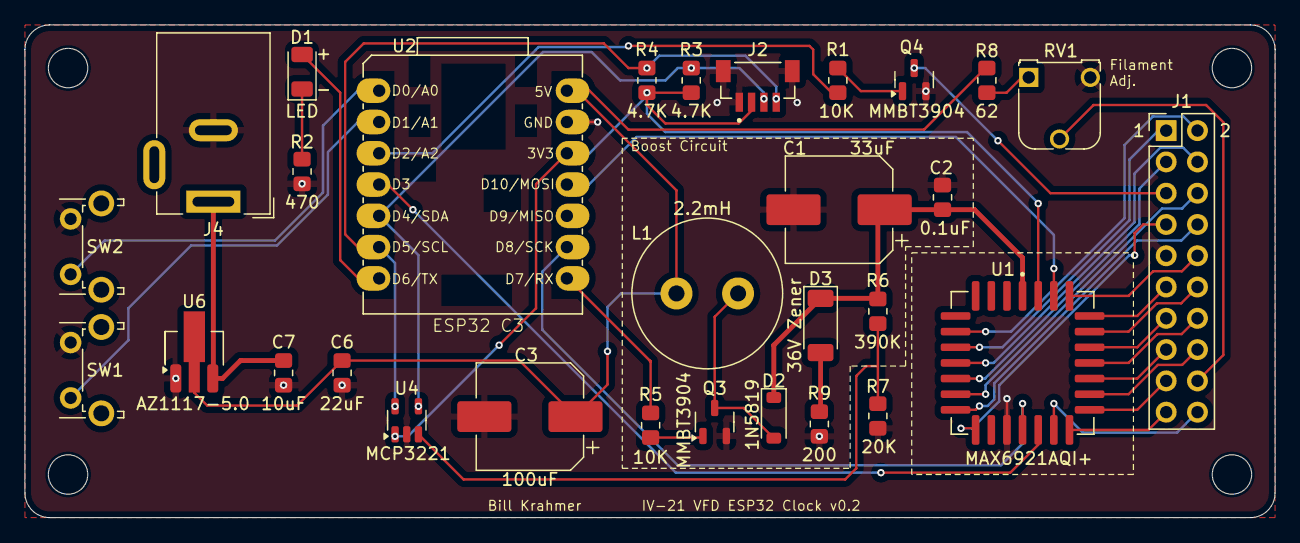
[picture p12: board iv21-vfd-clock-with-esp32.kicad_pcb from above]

Board: 2 copper layers, 101.5 x 40.0 mm, 30 parts (0 on the bottom side), 41 nets.

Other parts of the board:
R1: 10K; R_0805_2012Metric_Pad1.20x1.40mm_HandSolder

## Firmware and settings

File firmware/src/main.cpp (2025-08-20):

#include <Arduino.h>
#include <SPI.h>
#include <Wire.h>
#include <WiFi.h>
#include <WebServer.h>
#include <time.h>
#include "mcp3221.h"  // Abstraction for the MCP3221 ADC. This is a 12-bit ADC. Communicates over I2C.
#include "max6921.h"  // MAX6921 VFD driver class
#include "webui.h"
#include "credentials.h" // Wifi credentials.

// IV-21 Clock with an ESP32 MCU.
//
// This code is for a Seeeduino ESP32-C3 board with a MAX6921 VFD driver and MCP3221 ADC.
// This can be adapted for other ESP32 boards with minor changes.
// It initializes WiFi, time synchronization (via NTP server over Internet), PWM signal generation, and VFD display.
// It reads voltage from an MCP3221 ADC and adjusts the PWM duty cycle to maintain a target voltage for input into the VFD driver (MAX6921 IC).
// It displays the current time on a VFD and monitors the voltage every 40ms.

// Info about the Seeeduino XIAO ESP32-C3 board:
// https://wiki.seeedstudio.com/XIAO_ESP32C3_Getting_Started/

// Time configuration.
const char* NTP_SERVER = "pool.ntp.org";
const long GMT_OFFSET_SEC = -6 * 3600;                               // Central Time is GMT-5 (CST)
const int DAYLIGHT_OFFSET_SEC = 3600;                                // Daylight saving time offset (1 hour)
const int DST = 0;                                                   // Set to 1 to make daylight savings adjustments
bool timeSet = false;                                                // Flag to indicate if time has been set

// Flash message configuration
static bool flashMessageMode = true;                                 // Enable/disable flash message feature
const String flashMessages[] = {                                     // Array of messages to flash
  "COMRADE ",
  "SOVIET  ",
  "MARX    ",
  "LENIN   ",
  "STALIN  ",
  "WORKERS ",
  "UNITE   ",
  "POWER   ",
  "PARTY   ",
  "STATE   ",
  "RED DAWN",
  "FOR USSR",
  "GO RED  ",
  "OUR LAND"
};
const int numFlashMessages = sizeof(flashMessages) / sizeof(flashMessages[0]);
// const unsigned long FLASH_INTERVAL_MIN = 30000;                      // Minimum time between flashes (30 seconds)
// const unsigned long FLASH_INTERVAL_MAX = 120000;                     // Maximum time between flashes (2 minutes)
const unsigned long FLASH_INTERVAL_MIN = 10000;                       // Minimum time between flashes (in ms)
const unsigned long FLASH_INTERVAL_MAX = 25000;                      // Maximum time between flashes (in ms)
const unsigned long FLASH_DURATION = 500;                            // How long each message is displayed (in ms)
const unsigned long GLITCH_DURATION = 400;                           // How long the glitch effect lasts (in ms)
const unsigned long GLITCH_FRAME_TIME = 50;                          // Time between glitch frames (in ms)
unsigned long nextFlashTime = 0;                                     // When the next flash should occur
unsigned long flashEndTime = 0;                                      // When the current flash should end
unsigned long glitchEndTime = 0;                                     // When the glitch effect should end
unsigned long nextGlitchFrame = 0;                                   // When to show next glitch frame
bool isFlashing = false;                                             // Currently displaying a flash message
bool isGlitching = false;                                            // Currently showing glitch effect
bool isGlitchingOut = false;                                         // Currently showing glitch-out effect
int currentFlashIndex = 0;                                           // Index of current flash message
String currentGlitchText = "";                                       // Current glitch text being displayed

// VFD tube filament. Used to turn on the VFD tube filament heater. Applies voltage to transistor.
const int VFD_FILAMENT_PIN = D2;         // D2 pin is GPIO4 on Seeeduino ESP32-C3. Used to turn on the filament current to the VFD.
bool vfdFilamentEnabled = true;          // VFD filament state (can be controlled via web interface)

// Buttons
const int BUTTON_1_PIN = D1;             // D1 pin = GPIO3 on Seeeduino ESP32-C3. SW1 tactile momentary switch (connects to ground when pressed)
const int BUTTON_2_PIN = D0;             // D0 pin = GPIO2 on Seeeduino ESP32-C3. SW2 tactile momentary switch (connects to ground when pressed)
bool button1LastState = HIGH;           // Previous state of button 1 (HIGH when not pressed, LOW when pressed)
bool button2LastState = HIGH;           // Previous state of button 2 (HIGH when not pressed, LOW when pressed)
unsigned long button1LastDebounceTime = 0;  // Last time button 1 state changed
unsigned long button2LastDebounceTime = 0;  // Last time button 2 state changed
const unsigned long BUTTON_DEBOUNCE_DELAY = 50;  // Debounce delay in milliseconds

// LED
const int PWM_LED_INDICATOR_PIN = D6;    // D6 pin is GPIO21 on Seeeduino ESP32-C3. Used for PWM output to the brightness of the indicator LED/
const int PWM_LED_INDICATOR_CHANNEL = 1;

// Voltage Boost PWM configuration.
const int PWM_VBOOST_PIN = D7;           // D7 pin is GPIO20 on Seeeduino ESP32-C3. Used for PWM output to the booster circuit driving the VFD.
const int PWM_VBOOST_CHANNEL = 0;

// MAX6921 VFD IC configuration. This is the VFD driver IC that controls the IV-21 (or similar) VFD tube. Using SPI for Communication.
const int MAX6921_DIN_PIN = MOSI;        // MOSI pin (default) is GPIO10 on Seeeduino ESP32-C3. Used for SPI data input to MAX6921 IC.
const int MAX6921_CLK_PIN = SCK;         // SCK pin (default) is GPIO8 on Seeeduino ESP32-C3. Used for SPI clock signal to MAX6921 IC.
const int MAX6921_LOAD_PIN = D3;         // D3 pin is GPIO5 on Seeeduino ESP32-C3. Used for load signal to MAX6921 IC.

// MCP3221 ADC configuration. This is the ADC used to read the voltage from the booster circuit after the voltage divider. Using I2C for Communication.
const int MCP3221_SDA_PIN = SDA;        // SDA pin (default) is GPIO6 on Seeeduino ESP32-C3. Used for I2C communication with MCP3221 ADC.
const int MCP3221_SCL_PIN = SCL;        // SCL pin (default) is GPIO7 on Seeeduino ESP32-C3. Used for I2C communication with MCP3221 ADC.

// Voltage Boost PWM configuration.
const int MAX_VBOOST_PWM_DUTY_CYCLE = 220;                             // Maximum duty cycle for PWM signal (8-bit resolution, 0-255 range). In testing, above about 85% (220 for 8-bit value) yielded diminishing returns.
const int MIN_VBOOST_PWM_DUTY_CYCLE = 5;                               // Minimum duty cycle to keep the VFD lit (8-bit resolution, 0-255 range)
const int VBOOST_PWM_RESOLUTION = 8;                                   // 8-bit resolution (0-255 values)
const int VBOOST_PWM_DUTY_MAX_VALUE = pow(2, VBOOST_PWM_RESOLUTION);   // Convert bit resolution to max value (256 for 8-bit resolution)
const int VBOOST_PWM_FREQUENCY = 25000;                                // Default frequency in Hz
const float VBOOST_TARGET_VOLTAGE_V = 27;                              // 27 Volts
int boostDutyCycle = 110;                                              // Start with moderate duty cycle for IV-21

// Indicator LED PWM configuration.
const int LED_PWM_BIT_RESOLUTION = 8;                                  // 8-bit resolution (0-255 values)
const int LED_PWM_FREQUENCY_HZ = 5000;                                 // Frequency in Hz
const int LED_PWM_DUTY_CYCLE = 10;                                     // 128 = 50% duty cycle for 8-bit resolution (0-255)

// Voltage monitoring variables.
const int VOLTAGE_UPDATE_INTERVAL = 10;                                // Print voltage every 10 checks
const double VOLTAGE_MULTIPLIER = 390000.0 / 20000.0;                  // Voltage divider ratio based on the resistors used in the voltage divider circuit.
int voltageUpdateCounter = 0;
float currentActualVoltage = 0.0;                                       // Current actual voltage reading (calculated from voltage divider)

// Web server configuration
WebServer server(80);
bool isDisplayTimeMode = true;  // true = time, false = custom text
String customText = "HELLO   ";  // Default custom text (8 characters max)

// MCP3221 configuration. The MCP3221 is a 12-bit ADC with I2C interface.
const uint8_t MCP3221_ADDRESS = 0x4E;                                  // Typical default is 0x4D, but that did not work for this ADC.
const float MCP3221_REFERENCE_VOLTAGE_V = 3.3;                         // Reference voltage for MCP3221 in volts.
const float MCP3221_RESOLUTION = 12;                                   // MCP3221 is a 12-bit ADC, so the resolution is 2^12 = 4096.
MCP3221 mcp3221(MCP3221_ADDRESS, MCP3221_REFERENCE_VOLTAGE_V, MCP3221_RESOLUTION);

// Initialize digit pins array
uint8_t DIGIT_PINS[] = {
  15,  // Digit 1:     MAX6921 pin 7  (OUT-15)     (Adapter pin 1)      (IV-21 pin 6:  Digit 8 Grid)   
  1,   // Digit 2:     MAX6921 pin 25 (OUT-1)      (Adapter pin 11)     (IV-21 pin 15: Digit 7 Grid)   
  13,  // Digit 3:     MAX6921 pin 9  (OUT-13)     (Adapter pin 3)      (IV-21 pin 7:  Digit 6 Grid)   
  2,   // Digit 4:     MAX6921 pin 24 (OUT-2)      (Adapter pin 12)     (IV-21 pin 14: Digit 5 Grid)   
  14,  // Digit 5:     MAX6921 pin 8  (OUT-14)     (Adapter pin 4)      (IV-21 pin 8:  Digit 4 Grid)   
  0,   // Digit 6:     MAX6921 pin 26 (OUT-0)      (Adapter pin 10)     (IV-21 pin 13: Digit 3 Grid)      
  12,  // Digit 7:     MAX6921 pin 10 (OUT-12)     (Adapter pin 6)      (IV-21 pin 9:  Digit 2 Grid)   
  11,  // Digit 8:     MAX6921 pin 11 (OUT-11)     (Adapter pin 8)      (IV-21 pin 12: Digit 1 Grid)   
  10,  // Digit 9:     MAX6921 pin 12 (OUT-10)     (Adapter pin 7)      (IV-21 pin 11: Symbols Grid) (TODO: Currently not used/supported in this code)
  17,  // Digit 10:    MAX6921 pin 5  (OUT-17)     (NOT CONNECTED)
  18,  // Digit 11:    MAX6921 pin 4  (OUT-18)     (NOT CONNECTED)
  19,  // Digit 12:    MAX6921 pin 3  (OUT-19)     (NOT CONNECTED)
};

// TODO: Support digit 9 - symbols grid.
// TODO: Support digit 9 - symbols grid.
// TODO: Support digit 9 - symbols grid.

// Initialize segment pins array
uint8_t SEGMENT_PINS[] = {
  16,  // Segment A:             MAX6921 pin 6  (OUT-16)    (Adapter pin 2)       (IV-21 pin 5:  Segment A Anode)
  8,   // Segment B:             MAX6921 pin 18 (OUT-8)     (Adapter pin 19)      (IV-21 pin 3:  Segment B Anode)
  5,   // Segment C:             MAX6921 pin 21 (OUT-5)     (Adapter pin 15)      (IV-21 pin 18: Segment C Anode)
  3,   // Segment D:             MAX6921 pin 23 (OUT-3)     (Adapter pin 13)      (IV-21 pin 17: Segment D Anode)
  6,   // Segment E:             MAX6921 pin 20 (OUT-6)     (Adapter pin 16)      (IV-21 pin 19: Segment E Anode (Short lead))
  9,   // Segment F:             MAX6921 pin 17 (OUT-9)     (Adapter pin 20)      (IV-21 pin 4:  Segment Segment F Anode / Dot Symbol Anode)
  7,   // Segment G:             MAX6921 pin 19 (OUT-7)     (Adapter pin 17)      (IV-21 pin 2:  Segment G Anode / - Symbol Anode)
  4,   // Segment H (period):    MAX6921 pin 22 (OUT-4)     (Adapter pin 14)      (IV-21 pin 16: Segment DP Anode)
};

// Calculate array sizes
// const uint8_t NUM_DIGITS = sizeof(DIGIT_PINS) / sizeof(DIGIT_PINS[0]);
// const uint8_t NUM_SEGMENTS = sizeof(SEGMENT_PINS) / sizeof(SEGMENT_PINS[0]);
const uint8_t NUM_DIGITS = 8;
const uint8_t NUM_SEGMENTS = 8;

// MAX6921 VFD Display instance
MAX6921 vfdDisplay(MAX6921_DIN_PIN, MAX6921_CLK_PIN, MAX6921_LOAD_PIN, DIGIT_PINS, NUM_DIGITS, SEGMENT_PINS, NUM_SEGMENTS);

// Prototypes
void initWifi();
void initTime();
void initIndicatorLedPwmSignal(int dutyCycle);
void setIndicatorLedDutyCycle(int dutyCycle);
void printLocalTime();
String getFormattedTime();

// Voltage monitoring/adjustment functions
void initADC();
void initBoostPwmSignal();
int updateBoostDutyCycle(int currentDuty, bool printInfo = false);
void checkVoltage();

void updateDisplay();
void updateTimeDisplay();

// Flash message functions
void initFlashMessages();
void updateFlashMessages();
void scheduleNextFlash();
String generateGlitchText();

// VFD filament control functions
void initVfdFilament();
void setVfdFilament(bool enabled);
bool getVfdFilamentState();

// Button handling functions
void initButtons();
void updateButtons();
void handleButton1Press();
void handleButton2Press();

// Web server handlers
void initWebServer();
void updateCustomDisplay();
void handleRoot();
void handleToggleMode();
void handleToggleMessageMode();
void handleSetText();
#ifdef ENABLE_HOME_ASSISTANT
void handleFilamentToggle();
void handleFilamentOn();
void handleFilamentOff();
void handleFlashMessagesToggle();
void handleFlashMessagesOn();
void handleFlashMessagesOff();
void handleGetStatus();
#endif
void handleNotFound();

void setup()
{ 
  Serial.begin(115200);

#ifdef DEBUG
  // Wait for serial to be ready (helpful for debugging)
  delay(3000);
#endif

  Serial.println("Beginning setup...");

  // Init Indicator LED PWM
  Serial.println("Init Indicator LED PWM Signal (on)...");
  initIndicatorLedPwmSignal(LED_PWM_DUTY_CYCLE);

  Serial.println("Init WiFi...");
  initWifi();

  Serial.println("Init Time...");
  initTime();

  // Initialize web server
  Serial.println("Init Web Server...");
  initWebServer();

  // Initialize VFD Filament control
  Serial.println("Init VFD Filament control...");
  initVfdFilament();

  // Initialize buttons
  Serial.println("Init buttons...");
  initButtons();

  // Initialize I2C with explicit pins
  Serial.println("Init I2C for ADC...");
  Wire.begin(MCP3221_SDA_PIN, MCP3221_SCL_PIN);
  delay(100);

  // Init MCP3221 ADC
  Serial.println("Init MCP3221 ADC (using I2C)...");
  initADC();
  delay(100);

  // Init Voltage Booster PWM
  Serial.println("Init Boost PWM Signal...");
  initBoostPwmSignal();
  delay(500);
  
  // Init VFD
  Serial.println("Init MAX6921 VFD IC (using SPI)...");
  vfdDisplay.begin();

  // Init Flash Messages
  Serial.println("Init Flash Messages...");
  initFlashMessages();

  // Turn off indicator LED to indicate setup complete
  Serial.println("Turning off Indicator LED (setup complete)...");
  setIndicatorLedDutyCycle(0);

  Serial.println("Setup complete.");
  Serial.print("Web interface available at: http://");
  Serial.println(WiFi.localIP());
}

void loop()
{
  // Handle web server requests
  server.handleClient();
  
  // Update buttons
  updateButtons();

  // Update flash messages (only if enabled and in time mode)
  if (flashMessageMode && isDisplayTimeMode) {
    updateFlashMessages();
  }

  // Update VFD display
  updateDisplay();

  // Check and adjust voltage
  checkVoltage();
  
  // Refresh the display
  vfdDisplay.refreshDisplay();
}

void initWifi()
{
  // Initialize WiFi
  WiFi.mode(WIFI_STA);
  WiFi.begin(wifi_ssid, wifi_passphrase);
  Serial.println("Connecting to WiFi...");
  
  int count = 0;

  // Connection status monitoring
  while (WiFi.status() != WL_CONNECTED)
  {
    delay(500);
    Serial.print(".");
    count++;

    if (count >= 20) // Timeout after 10 seconds
    {
      Serial.println("Failed to connect to WiFi. Check credentials and network.");
      return;
    }
  }

  Serial.println();
  Serial.print("Connected to WiFi! IP address: ");
  Serial.println(WiFi.localIP());
}

void initTime()
{
  Serial.println("Initializing time from NTP server...");
  
  // Configure time with NTP server and timezone
  configTime(GMT_OFFSET_SEC, DAYLIGHT_OFFSET_SEC, NTP_SERVER);
  
  // Wait for time to be set
  struct tm timeinfo;
  int attempts = 0;
  while (!getLocalTime(&timeinfo) && attempts < 10)
  {
    Serial.println("Failed to obtain time, retrying...");
    delay(500);
    attempts++;
  }
  
  if (attempts >= 10)
  {
    Serial.println("Failed to obtain time after 10 attempts!");
    timeSet = false;
  }
  else
  {
    Serial.println("Time synchronized successfully!");
    printLocalTime();
    timeSet = true;
  }
}

void initWebServer()
{
  // Define web server routes
  server.on("/", handleRoot);
  server.on("/toggle", handleToggleMode);
  server.on("/toggleFlashMessage", handleToggleMessageMode);
  server.on("/settext", HTTP_POST, handleSetText);
  
#ifdef ENABLE_HOME_ASSISTANT
  // Home Assistant compatible endpoints
  server.on("/filament/toggle", handleFilamentToggle);
  server.on("/filament/on", handleFilamentOn);
  server.on("/filament/off", handleFilamentOff);
  server.on("/flashmessages/toggle", handleFlashMessagesToggle);
  server.on("/flashmessages/on", handleFlashMessagesOn);
  server.on("/flashmessages/off", handleFlashMessagesOff);
  server.on("/status", handleGetStatus);
#endif
  
  server.onNotFound(handleNotFound);
  
  // Start the server
  server.begin();
  Serial.println("Web server started");
}

void initADC()
{
  if (mcp3221.begin())
  {
    Serial.println("MCP3221 found and ready!");
    Serial.print("I2C Address: 0x");
    Serial.println(mcp3221.getAddress(), HEX);
    Serial.print("Reference Voltage: ");
    Serial.print(mcp3221.getVref(), 2);
    Serial.println(" V");
    Serial.print("Resolution: ");
    Serial.println(mcp3221.getResolution());
    Serial.print("Max Value: ");
    Serial.println(mcp3221.getMaxValue());
  }
  else
  {
    Serial.println("MCP3221 not found. Check connections and address.");
  }
}

void initBoostPwmSignal()
{
  // Set up LEDC PWM using Arduino ESP32 3.x API
  uint32_t actualBoostPwmFreq = ledcSetup(PWM_VBOOST_CHANNEL, VBOOST_PWM_FREQUENCY, VBOOST_PWM_RESOLUTION);
  ledcAttachPin(PWM_VBOOST_PIN, PWM_VBOOST_CHANNEL);
  // Set initial duty cycle
  ledcWrite(PWM_VBOOST_CHANNEL, boostDutyCycle);
  
  // Debug output to verify PWM configuration
  Serial.print("Boost PWM Channel: ");
  Serial.println(PWM_VBOOST_CHANNEL);
  Serial.print("Boost PWM Pin (D7/GPIO20): ");
  Serial.println(PWM_VBOOST_PIN);
  Serial.print("Requested frequency: ");
  Serial.print(VBOOST_PWM_FREQUENCY);
  Serial.println(" Hz");
  Serial.print("Actual frequency: ");
  Serial.print(actualBoostPwmFreq);
  Serial.println(" Hz");
  Serial.print("PWM Resolution: ");
  Serial.print(VBOOST_PWM_RESOLUTION);
  Serial.println(" bits");
  Serial.print("Initial duty cycle: ");
  Serial.print(boostDutyCycle);
  Serial.print("/");
  Serial.print(VBOOST_PWM_DUTY_MAX_VALUE - 1);
  Serial.print(" (");
  Serial.print((boostDutyCycle * 100.0) / (VBOOST_PWM_DUTY_MAX_VALUE - 1), 1);
  Serial.println("%)");
}

void initIndicatorLedPwmSignal(int dutyCycle)
{
  // Set up LEDC PWM using Arduino ESP32 3.x API
  uint32_t actualLedPwmFreq = ledcSetup(PWM_LED_INDICATOR_CHANNEL, LED_PWM_FREQUENCY_HZ, LED_PWM_BIT_RESOLUTION);
  ledcAttachPin(PWM_LED_INDICATOR_PIN, PWM_LED_INDICATOR_CHANNEL);
  // Set initial duty cycle
  ledcWrite(PWM_LED_INDICATOR_CHANNEL, dutyCycle);

  // Debug output to verify PWM configuration
  Serial.print("LED Indicator PWM Channel: ");
  Serial.println(PWM_LED_INDICATOR_CHANNEL);
  Serial.print("LED Indicator PWM Pin (D6/GPIO19): ");
  Serial.println(PWM_LED_INDICATOR_PIN);
  Serial.print("Requested frequency: ");
  Serial.print(LED_PWM_FREQUENCY_HZ);
  Serial.println(" Hz");
  Serial.print("Actual frequency: ");
  Serial.print(actualLedPwmFreq);
  Serial.println(" Hz");
  Serial.print("PWM Resolution: ");
  Serial.print(LED_PWM_BIT_RESOLUTION);
  Serial.println(" bits");
  Serial.print("Initial duty cycle: ");
  Serial.print(dutyCycle);
  Serial.print("/");
  Serial.print((1 << LED_PWM_BIT_RESOLUTION) - 1);
  Serial.print(" (");
  Serial.print((dutyCycle * 100.0) / ((1 << LED_PWM_BIT_RESOLUTION) - 1), 1);
  Serial.println("%)");
}

void setIndicatorLedDutyCycle(int dutyCycle)
{
  // Only change the duty cycle, don't reconfigure the PWM channel
  ledcWrite(PWM_LED_INDICATOR_CHANNEL, dutyCycle);
  Serial.print("LED Indicator duty cycle changed to: ");
  Serial.print(dutyCycle);
  Serial.print("/");
  Serial.print((1 << LED_PWM_BIT_RESOLUTION) - 1);
  Serial.print(" (");
  Serial.print((dutyCycle * 100.0) / ((1 << LED_PWM_BIT_RESOLUTION) - 1), 1);
  Serial.println("%)");
}

void initFlashMessages()
{
  // Schedule the first flash message
  scheduleNextFlash();
  Serial.println("Flash messages initialized");
  Serial.print("Flash message mode: ");
  Serial.println(flashMessageMode ? "ENABLED" : "DISABLED");
  Serial.print("Number of flash messages: ");
  Serial.println(numFlashMessages);
}

void scheduleNextFlash()
{
  // Generate a random interval between min and max
  unsigned long interval = random(FLASH_INTERVAL_MIN, FLASH_INTERVAL_MAX + 1);
  nextFlashTime = millis() + interval;
  
  Serial.print("Next flash scheduled in ");
  Serial.print(interval / 1000);
  Serial.println(" seconds");
}
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

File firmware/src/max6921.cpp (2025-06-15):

#include "max6921.h"

MAX6921::MAX6921(int dinPin, int clkPin, int loadPin,
                 const uint8_t* digitPinMap, uint8_t numDigits,
                 const uint8_t* segmentPinMap, uint8_t numSegments) 
  : dinPin(dinPin), clkPin(clkPin), loadPin(loadPin),
    numDigits(numDigits), numSegments(numSegments),
    spiSettings(500000, MSBFIRST, SPI_MODE0), currentDigit(0), 
    lastRefresh(0)
{
  // Validate input parameters
  if (numDigits > MAX_DIGITS) {
    this->numDigits = MAX_DIGITS;
  }
  if (numSegments > MAX_SEGMENTS) {
    this->numSegments = MAX_SEGMENTS;
  }
  
  // Copy digit pins array
  for (int i = 0; i < this->numDigits; i++) {
    digitPins[i] = digitPinMap[i];
  }
  
  // Copy segment pins array  
  for (int i = 0; i < this->numSegments; i++) {
    segmentPins[i] = segmentPinMap[i];
  }
  
  // Initialize display buffer
  strcpy(displayBuffer, "        ");
  for (int i = 0; i < numDigits; i++) {
    digitsWithDots[i] = false;
  }
  
  // Initialize character map
  initCharMap();
}

bool MAX6921::begin()
{
  // Initialize the LOAD pin
  pinMode(loadPin, OUTPUT);
  digitalWrite(loadPin, HIGH);  // Start with LOAD high
  
  // Initialize SPI
  SPI.begin(clkPin, -1, dinPin, -1);  // CLK, MISO (not used), MOSI, SS (not used)
  
  // Clear all outputs
  writeToMAX6921(0);
  delay(50);
  
  return true;
}

void MAX6921::initCharMap()
{
  // Initialize all to 0
  for (int i = 0; i < 128; i++) {
    charMap[i] = 0;
  }
  
  // Numbers
  charMap['0'] = 0b00111111;  // ABCDEF
  charMap['1'] = 0b00000110;  // BC
  charMap['2'] = 0b01011011;  // ABDEG
  charMap['3'] = 0b01001111;  // ABCDG
  charMap['4'] = 0b01100110;  // BCFG
  charMap['5'] = 0b01101101;  // ACDFG
  charMap['6'] = 0b01111101;  // ACDEFG
  charMap['7'] = 0b00000111;  // ABC
  charMap['8'] = 0b01111111;  // ABCDEFG
  charMap['9'] = 0b01101111;  // ABCDFG
  
  // Letters (A-Z)
  charMap['A'] = 0b01110111;  // ABCEFG
  charMap['B'] = 0b01111100;  // CDEFG
  charMap['C'] = 0b00111001;  // ADEF
  charMap['D'] = 0b01011110;  // BCDEG
  charMap['E'] = 0b01111001;  // ADEFG
  charMap['F'] = 0b01110001;  // AEFG
  charMap['G'] = 0b00111101;  // ACDEF
  charMap['H'] = 0b01110110;  // BCEFG
  charMap['I'] = 0b00110000;  // EF
  charMap['J'] = 0b00011110;  // BCDE
  charMap['K'] = 0b01110110;  // BCEFG (same as 'H')
  charMap['L'] = 0b00111000;  // DEF
  charMap['M'] = 0b00010101;  // ACE (approximation)
  charMap['N'] = 0b00110111;  // ABCEF
  charMap['O'] = 0b00111111;  // ABCDEF
  charMap['P'] = 0b01110011;  // ABEFG
  charMap['Q'] = 0b01100111;  // ABCFG
  charMap['R'] = 0b00110011;  // ABEF
  charMap['S'] = 0b01101101;  // ACDFG
  charMap['T'] = 0b01111000;  // DEFG
  charMap['U'] = 0b00111110;  // BCDEF
  charMap['V'] = 0b00011110;  // BCDE (approximation)
  charMap['W'] = 0b00101010;  // BDG (approximation)
  charMap['X'] = 0b01110110;  // BCEFG (approximation) (same as 'H')
  charMap['Y'] = 0b01101110;  // BCDFG
  charMap['Z'] = 0b01011011;  // ABDEG (same as '2')
  
  // Special characters
  charMap[' '] = 0b00000000;  // All off
  charMap['-'] = 0b01000000;  // G only
  charMap['_'] = 0b00001000;  // D only
  charMap['.'] = 0b10000000;  // H only (decimal point)
  charMap[':'] = 0b01001000;  // DG
  charMap['='] = 0b01001000;  // DG (same as colon)
  charMap['!'] = 0b10000110;  // BC with decimal
  charMap['?'] = 0b11010011;  // ABGEH
  charMap['\''] = 0b00000010; // B only
  charMap['"'] = 0b00100010;  // BF
  charMap['<'] = 0b01110000;  // EFG
  charMap['>'] = 0b01000011;  // ABG
  charMap['['] = 0b00111001;  // ADEF
  charMap[']'] = 0b00001111;  // ABCD
  charMap['/'] = 0b01010010;  // BEG
  charMap['\\'] = 0b01100100; // CFG
}

void MAX6921::writeToMAX6921(uint32_t data)
{
  // Sends 3 bytes to the MAX6921
  // Stores them as [byte0, byte1, byte2] where:
  // byte0 contains bits for pins 16-23 (but reversed)
  // byte1 contains bits for pins 8-15 (but reversed)
  // byte2 contains bits for pins 0-7 (but reversed)
  
  // Extract bytes from our data
  uint8_t byte0 = (data >> 16) & 0xFF;  // Bits 23-16
  uint8_t byte1 = (data >> 8) & 0xFF;   // Bits 15-8
  uint8_t byte2 = data & 0xFF;          // Bits 7-0
  
  // Begin SPI transaction
  SPI.beginTransaction(spiSettings);
  
  // Pull LOAD low to start data transfer
  digitalWrite(loadPin, LOW);

  SPI.transfer(byte0);  // Send bits 23-16 first
  SPI.transfer(byte1);  // Send bits 15-8
  SPI.transfer(byte2);  // Send bits 7-0 last
  
  // Pull LOAD high to latch the data
  digitalWrite(loadPin, HIGH);
  
  // End SPI transaction
  SPI.endTransaction();
}

void MAX6921::displayDigit(uint8_t digitIndex, uint8_t segments)
{
  if (digitIndex >= numDigits) return;  // Bounds check
  
  // We need to create the full pin activation pattern
  uint8_t bytes[3] = {0, 0, 0};
  
  // Set the digit pin (cathode)
  uint8_t digitPin = digitPins[digitIndex];
  uint8_t true_order = 23 - digitPin;
  uint8_t target_byte = true_order / 8;
  uint8_t target_bit = true_order % 8;
  bytes[target_byte] |= (1 << (7 - target_bit));
  
  // Now handle segments
  // segment_order = "ABCDEFGH" maps to segmentPins array
  // So if segments has bit 0 set, we activate segmentPins[0] (segment A)
  // If segments has bit 1 set, we activate segmentPins[1] (segment B), etc.
  
  for (int segIndex = 0; segIndex < numSegments; segIndex++) {
    if (segments & (1 << segIndex)) {
      uint8_t segmentPin = segmentPins[segIndex];
      uint8_t seg_true_order = 23 - segmentPin;
      uint8_t seg_target_byte = seg_true_order / 8;
      uint8_t seg_target_bit = seg_true_order % 8;
      bytes[seg_target_byte] |= (1 << (7 - seg_target_bit));
    }
  }
  
  // Now convert bytes array to uint32_t for writeToMAX6921
  uint32_t data = ((uint32_t)bytes[0] << 16) | ((uint32_t)bytes[1] << 8) | bytes[2];
  
  writeToMAX6921(data);
}

void MAX6921::refreshDisplay()
{
  // Multiplex the display at ~1kHz (1ms per digit)
  if (micros() - lastRefresh >= 1000) {
    // Turn off all outputs first to prevent ghosting
    //writeToMAX6921(0);

    // Get the character to display
    char ch = displayBuffer[currentDigit];
    uint8_t segments = 0;

    // Look up segments for this character
    if (ch >= 0 && ch < 128) {
      segments = charMap[(uint8_t)ch];
    }

    // Check if the next character is a decimal point
    if (currentDigit < numDigits && digitsWithDots[currentDigit]) {
      segments |= 0x80;  // Turn on decimal point
    }

    // Display the digit (including spaces as blank)
    displayDigit(currentDigit, segments);

    currentDigit = (currentDigit + 1) % numDigits;

    lastRefresh = micros();
  }
}
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

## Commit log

2025-06-15 Initial "public" commit of working project.
    [4328.step, IV-21VFDsub.kicad_pcb, bom_IV-21VFDsub.csv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]
2025-06-16 PDF of schematic.
    [iv21-vfd-clock-with-esp32.kicad_sch]
2025-06-16 Update interactive BOM file.
2025-06-16 Add pdfs (#1)
    * pdfs. move some seeeduino text.
    * Updating PCB PDFs
    [iv21-vfd-clock-with-esp32.kicad_pcb]
2025-06-18 Fixed rounded corner to match other rounded corner.
    [IV-21VFDsub.kicad_pcb]
2025-08-18 Fixed LEDC functionc calls. Using ledcSetup() and ledcAttachPin() functions instead of ledcAttach().
    While using this version of the LEDC lib, the channel number is passed into ledcWrite() instead of the pin number.
    [main.cpp]
2025-08-20 Add home assistant functionality (#4)
    * Renamed readme file.
    * Initial REST API suport for Home Assistant.
    * Update IPs in docs.
    * Debug button presses.
    * /status returns button state as well, now.
    * Fix fialment toggle via HA.
    * Expose FlashMessagesToggle
    * actual_voltage report to HA.
    * Fixing voltage boost pwm
    * use the older (more precise) pwm resolution.
    * Adjust target voltage to 27V and update boost duty cycle reporting in status response
    * Remove unused yaml.
    * Make Home Assistant functionality optional with a build flag.
    * Make flash message a little less frequent.
    [main.cpp]
